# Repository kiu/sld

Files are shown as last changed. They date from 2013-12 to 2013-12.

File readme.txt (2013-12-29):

SLDongle (SLD) provides an inexpensive entry into the world of microcontroller development.
http://schoar.de/tinkering/sld

Control LEDs from host:
    1. Plug SLD into USB port
    2. Pipe 13 bytes to /src/usbhost/sldtool

Compile own application:
    - MCU = atmega88p
    - F_CPU = 12000000
    - Max size = 8192 bytes (flash) - 2048 bytes (bootloader) = 6144 bytes

Flash own application:
    1. Hold button
    2. Plug SLD into USB port
    3. Wait until host has enumarated the emulated USBasp
    4. Release button
    5. Flash your hex file (avrdude -p atmega88p -c usbasp -U flash:w:my.hex)

Directory structure:
    /pcb		Schematic and board as Eagle CAD files
    /pcb/img		Schematic and board as PNG files
    /pcb/gerber		Board as Gerber files

    /src/bootloader	Bootloader running on the device
    /src/contrib	Third party contributions
    /src/firmware	Main app running on the device
    /src/helper		Helper scripts for mass flashing
    /src/simple		A simple example app
    /src/usbhost	Host tool to control LEDs

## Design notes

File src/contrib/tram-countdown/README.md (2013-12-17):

# Tram Countdown

Checks when your tram leaves from Trappentreustr. and switches as many lights on as there are minutes left.

For e.g. Line 18 to Effnerplatz, run:

```
./tram-countdown 18 Effnerplatz
```

This runs with your Mac's system Ruby but you need to install the `mvg-live` gem:

```
sudo /usr/bin/gem install mvg-live
```

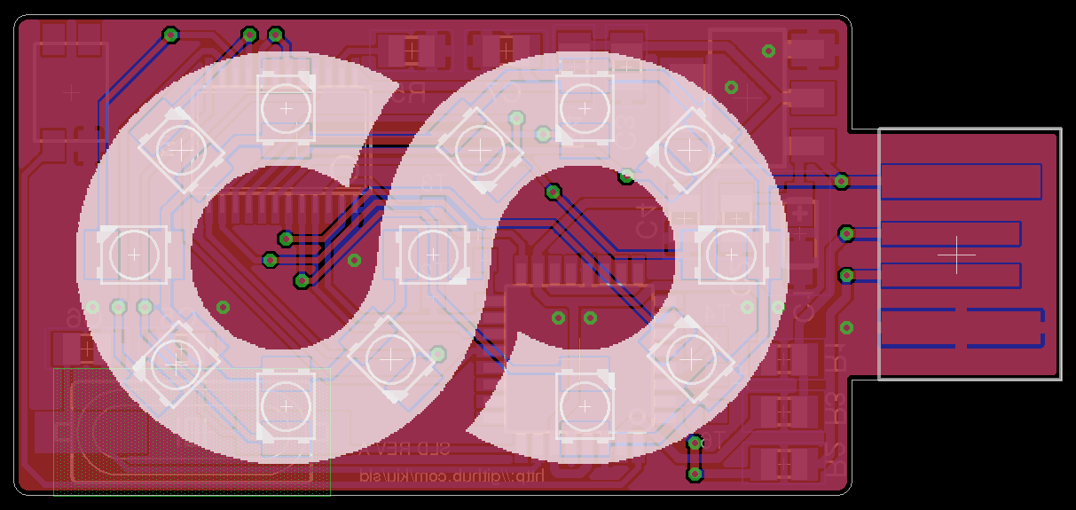
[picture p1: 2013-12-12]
pcb/img/sld_brd.png

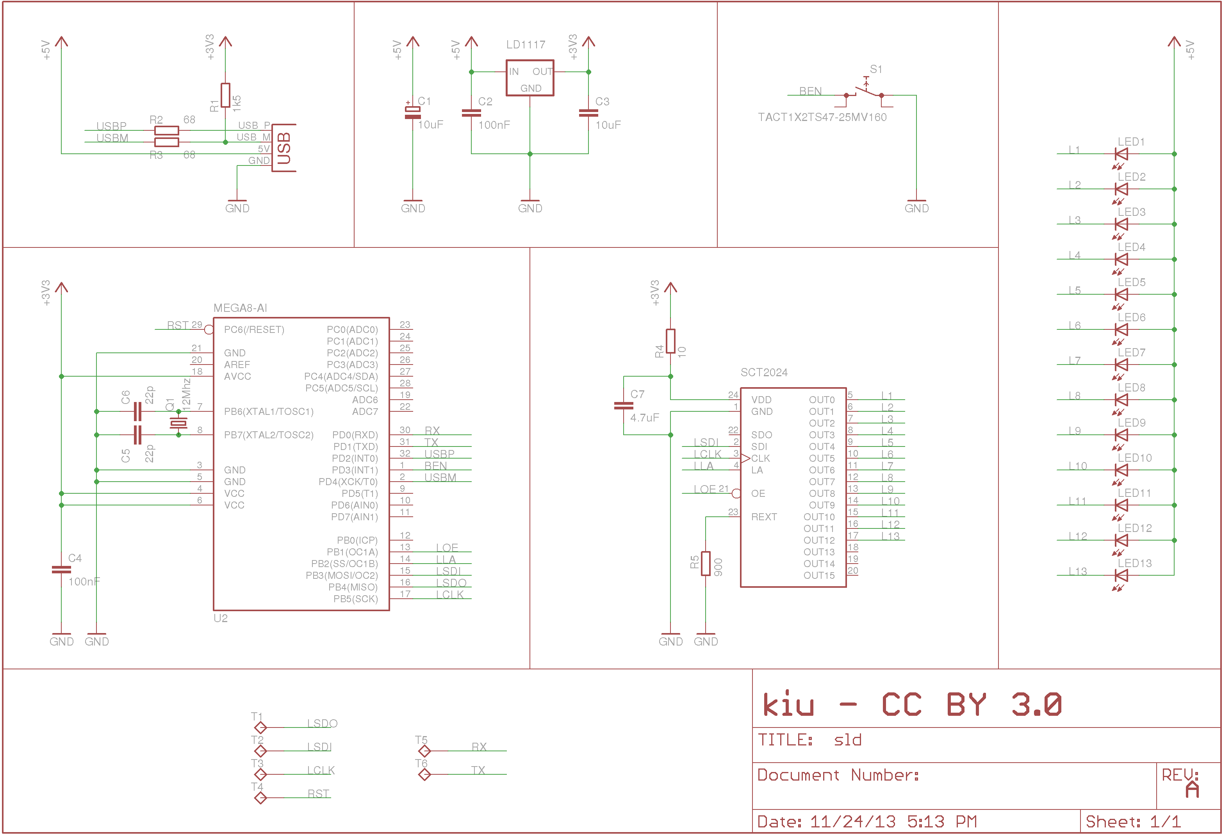
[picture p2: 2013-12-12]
pcb/img/sld_sch.png

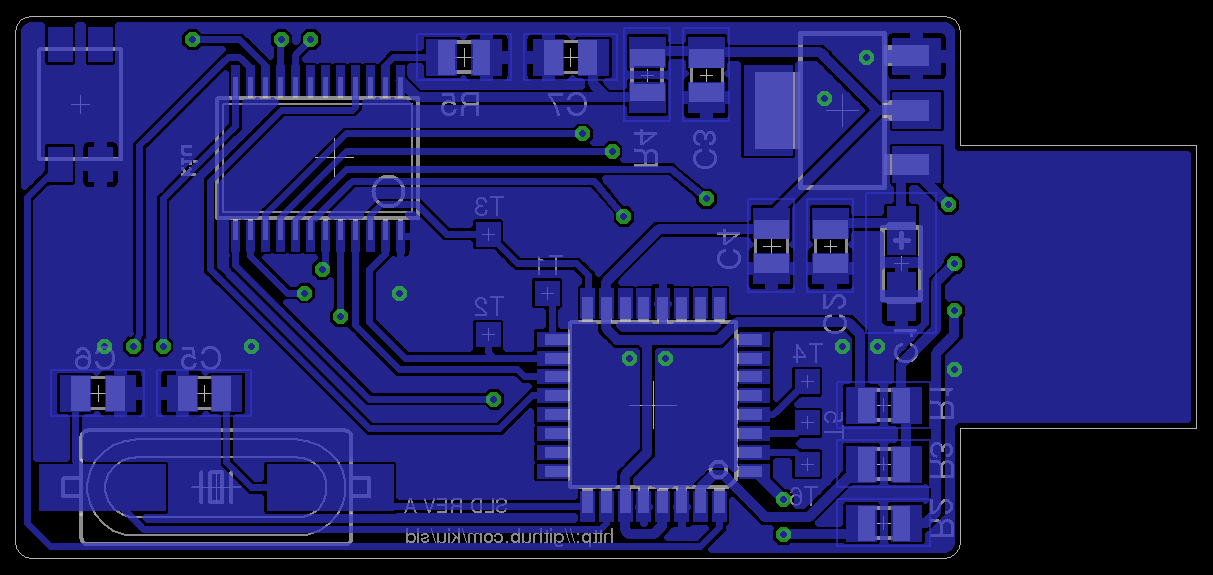
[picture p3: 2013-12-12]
pcb/img/sld_brd_btm.png

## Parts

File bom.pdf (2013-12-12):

BOM

Page 1

Ordered | Description | Qty | Price | Price (sum) | Id | Link
x | ATMega88PA-AU TQFP32 | 1 | 30 | 30 | 0.92 € | 27.63 €
x | 12Mhz crystal HC49 | 1 | 30 | 30 | 0.27 € | 8.18 €
x | 22pF 0805 | 2 | 30 | 100 | 0.01 € | 0.83 €
x | 100nF 0805 | 2 | 30 | 100 | 0.01 € | 0.60 €
x | White LED 3528 | 13 | 30 | 500 | 0.06 € | 29.75 €
x | 16 channel LED driver SSOP24 | 1 | 30 | 30 | 0.31 € | 9.28 €
x | 10R 0805 | 1 | 30 | 100 | 0.01 € | 0.71 €
x | 1k2 0805 | 1 | 30 | 100 | 0.01 € | 0.71 €
x | 4.7uF | 1 | 30 | 100 | 0.02 € | 2.02 €
x | Tactile Switch | 1 | 30 | 30 | 0.21 € | 6.25 €
x | LDO 3V3 | 1 | 30 | 30 | 0.12 € | 3.68 €
x | 10uF 0805 | 1 | 30 | 100 | 0.02 € | 1.55 €
x | | 1 | 30 | 30 | 0.07 € | 2.18 €
x | 68R 0805 | 2 | 30 | 100 | 0.01 € | 0.71 €
x | 1k5 0805 | 1 | 30 | 100 | 0.01 € | 0.71 €
x | Shipping | 1 | 1 | 1 | 5.90 € | 5.90 € | ---
x | PCB 50x50x2 blue | 1 | 30 | 1 | 88.00 € | 88.00 € | ---
| | | | | | SUM
| | | | | | 188.70 € | 6.29 €
Req | Mul
| ATMEGA88PA-AU (http://www.tme.eu/de/details/atmega88pa-au/mikrocontroller-atmel-avr-smd/atmel/) | http://www.tme.eu
| 12.00M-SMDHC49S (http://www.tme.eu/de/details/12.00m-smdhc49s/quarzresonatoren-smd/yic/) | http://www.tme.eu
| CL21C220JBANNNC (http://www.tme.eu/de/details/cl21c220jbannnc/kondensatoren-mlcc-smd-0805/samsung/) | http://www.tme.eu
| CC0805JRX7R9104 (http://www.tme.eu/de/details/cc0805jrx7r9104/kondensatoren-mlcc-smd-0805/yageo/cc0805jrx7r9bb104/) | http://www.tme.eu
| WW-WTA30TS-Q (http://www.tme.eu/de/details/ww-wta30ts-q/led-dioden-smd-plcc/wah-wang-holding/) | http://www.tme.eu
| SCT2024CSSG (http://www.tme.eu/de/details/sct2024cssg/led-treiber/starchips-technology/) | http://www.tme.eu
| RC0805FR-0710R (http://www.tme.eu/de/details/rc0805fr-0710r/widerstande-smd-0805/yageo/rc0805fr-0710rl/) | http://www.tme.eu
| SMD0805-1K2-1% (http://www.tme.eu/de/details/smd0805-1k2-1%25/widerstande-smd-0805/royal-ohm/0805s8f1201t5e/) | http://www.tme.eu
| CL21A475KOFNNNE (http://www.tme.eu/de/details/cl21a475kofnnne/kondensatoren-mlcc-smd-0805/samsung/) | http://www.tme.eu
| TS4725MV160 (http://www.tme.eu/de/details/ts4725mv160/tact-pcb-mikroschalter/canal-electronic/ts47-25mv160/) | http://www.tme.eu
| LD1117S33TR (http://www.tme.eu/de/details/ld1117s33tr/ungeregelte-spannungsstabilisatoren-ldo/st-microelectronics/) | http://www.tme.eu
| CC0805KKX5R5106 (http://www.tme.eu/de/details/cc0805kkx5r5106/kondensatoren-mlcc-smd-0805/yageo/cc0805kkx5r5bb106/) | http://www.tme.eu
10uF Tantal | TAJA106K010R (http://www.tme.eu/de/details/taja106k010r/tantal-kondensatoren-smd/avx/taja106k010rnj/) | http://www.tme.eu
| SMD0805-68R-1% (http://www.tme.eu/de/details/smd0805-68r-1%25/widerstande-smd-0805/royal-ohm/0805s8f680jt5e/) | http://www.tme.eu
| SMD0805-1K5-1% (http://www.tme.eu/de/details/smd0805-1k5-1%25/widerstande-smd-0805/royal-ohm/0805s8f1501t5e/) | http://www.tme.eu
| | http://www.tme.eu
| | http://www.seeedstudio.com
A | B | C | D | E | F | G | H | I
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
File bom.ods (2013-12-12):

Ordered | Description | Req | Mul | Qty | Price | Price (sum) | Id | Link
x | ATMega88PA-AU TQFP32 | 1 | 30 | 30 | 0.92 € | 27.63 € | ATMEGA88PA-AU (http://www.tme.eu/de/details/atmega88pa-au/mikrocontroller-atmel-avr-smd/atmel/) | http://www.tme.eu
x | 12Mhz crystal HC49 | 1 | 30 | 30 | 0.27 € | 8.18 € | 12.00M-SMDHC49S (http://www.tme.eu/de/details/12.00m-smdhc49s/quarzresonatoren-smd/yic/) | http://www.tme.eu
x | 22pF 0805 | 2 | 30 | 100 | 0.01 € | 0.83 € | CL21C220JBANNNC (http://www.tme.eu/de/details/cl21c220jbannnc/kondensatoren-mlcc-smd-0805/samsung/) | http://www.tme.eu
x | 100nF 0805 | 2 | 30 | 100 | 0.01 € | 0.60 € | CC0805JRX7R9104 (http://www.tme.eu/de/details/cc0805jrx7r9104/kondensatoren-mlcc-smd-0805/yageo/cc0805jrx7r9bb104/) | http://www.tme.eu
x | White LED 3528 | 13 | 30 | 500 | 0.06 € | 29.75 € | WW-WTA30TS-Q (http://www.tme.eu/de/details/ww-wta30ts-q/led-dioden-smd-plcc/wah-wang-holding/) | http://www.tme.eu
x | 16 channel LED driver SSOP24 | 1 | 30 | 30 | 0.31 € | 9.28 € | SCT2024CSSG (http://www.tme.eu/de/details/sct2024cssg/led-treiber/starchips-technology/) | http://www.tme.eu
x | 10R 0805 | 1 | 30 | 100 | 0.01 € | 0.71 € | RC0805FR-0710R (http://www.tme.eu/de/details/rc0805fr-0710r/widerstande-smd-0805/yageo/rc0805fr-0710rl/) | http://www.tme.eu
x | 1k2 0805 | 1 | 30 | 100 | 0.01 € | 0.71 € | SMD0805-1K2-1% (http://www.tme.eu/de/details/smd0805-1k2-1%25/widerstande-smd-0805/royal-ohm/0805s8f1201t5e/) | http://www.tme.eu
x | 4.7uF | 1 | 30 | 100 | 0.02 € | 2.02 € | CL21A475KOFNNNE (http://www.tme.eu/de/details/cl21a475kofnnne/kondensatoren-mlcc-smd-0805/samsung/) | http://www.tme.eu
x | Tactile Switch | 1 | 30 | 30 | 0.21 € | 6.25 € | TS4725MV160 (http://www.tme.eu/de/details/ts4725mv160/tact-pcb-mikroschalter/canal-electronic/ts47-25mv160/) | http://www.tme.eu
x | LDO 3V3 | 1 | 30 | 30 | 0.12 € | 3.68 € | LD1117S33TR (http://www.tme.eu/de/details/ld1117s33tr/ungeregelte-spannungsstabilisatoren-ldo/st-microelectronics/) | http://www.tme.eu
x | 10uF 0805 | 1 | 30 | 100 | 0.02 € | 1.55 € | CC0805KKX5R5106 (http://www.tme.eu/de/details/cc0805kkx5r5106/kondensatoren-mlcc-smd-0805/yageo/cc0805kkx5r5bb106/) | http://www.tme.eu
x | 10uF Tantal | 1 | 30 | 30 | 0.07 € | 2.18 € | TAJA106K010R (http://www.tme.eu/de/details/taja106k010r/tantal-kondensatoren-smd/avx/taja106k010rnj/) | http://www.tme.eu
x | 68R 0805 | 2 | 30 | 100 | 0.01 € | 0.71 € | SMD0805-68R-1% (http://www.tme.eu/de/details/smd0805-68r-1%25/widerstande-smd-0805/royal-ohm/0805s8f680jt5e/) | http://www.tme.eu
x | 1k5 0805 | 1 | 30 | 100 | 0.01 € | 0.71 € | SMD0805-1K5-1% (http://www.tme.eu/de/details/smd0805-1k5-1%25/widerstande-smd-0805/royal-ohm/0805s8f1501t5e/) | http://www.tme.eu
x | Shipping | 1 | 1 | 1 | 5.90 € | 5.90 € | --- | http://www.tme.eu
x | PCB 50x50x2 blue | 1 | 30 | 1 | 88.00 € | 88.00 € | --- | http://www.seeedstudio.com
 |  |  |  |  |  | SUM
 |  |  |  |  |  | 188.70 € | 6.29 €

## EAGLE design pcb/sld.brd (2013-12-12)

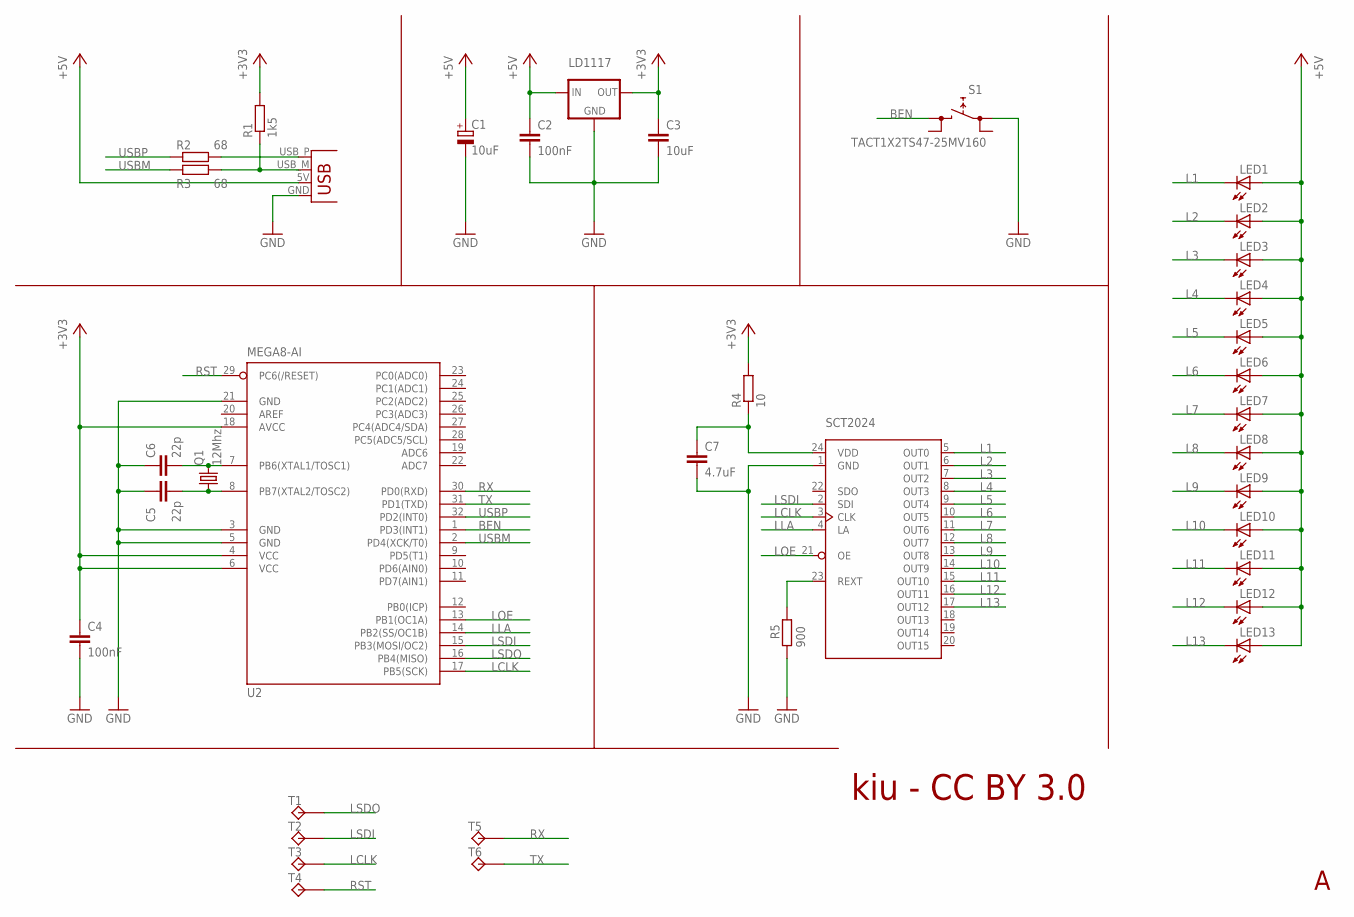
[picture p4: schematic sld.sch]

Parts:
C1: 10uF; CT3216
C2, C4: 100nF; C0805
C3: 10uF; C0805
C5, C6: 22p; C0805
C7: 4.7uF; C0805
JP1: USBPCB; USB-A-PCB
LED1, LED2, LED3, LED4, LED5, LED6, LED7, LED8, LED9, LED10, LED11, LED12, LED13: LEDKA-3528ASYC; KA-3528ASYC
Q1: 12Mhz; HC49UP
R1: 1k5; R0805
R2, R3: 68; R0805
R4: 10; R0805
R5: 900; R0805
S1: TACT1X2TS47-25MV160; TACT1.7X5.15
T1, T2, T3, T4, T5, T6: PAD; PAD-1X1
U1: LD1117; SOT223
U2: MEGA8-AI; TQFP32-08
U3: SCT2024; SSOP24

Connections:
+3V3: C3.1, C4.1, R1.2, R4.2, U1.2 (OUT), U2.4 (VCC), U2.6 (VCC), U2.18 (AVCC)
+5V: C1.+, C2.1, JP1.5V (VBUS), LED1.A, LED2.A, LED3.A, LED4.A, LED5.A, LED6.A, LED7.A, LED8.A, LED9.A, LED10.A, LED11.A, LED12.A, LED13.A, U1.3 (IN)
BEN: S1.2 (1), U2.1 (PD3(INT1))
GND: C1.-, C2.2, C3.2, C4.2, C5.1, C6.1, C7.2, JP1.GND, R5.2, S1.1 (0), U1.1 (GND), U2.3 (GND), U2.5 (GND), U2.21 (GND), U3.1 (GND)
L1: LED1.C, U3.5 (OUT0)
L2: LED2.C, U3.6 (OUT1)
L3: LED3.C, U3.7 (OUT2)
L4: LED4.C, U3.8 (OUT3)
L5: LED5.C, U3.9 (OUT4)
L6: LED6.C, U3.10 (OUT5)
L7: LED7.C, U3.11 (OUT6)
L8: LED8.C, U3.12 (OUT7)
L9: LED9.C, U3.13 (OUT8)
L10: LED10.C, U3.14 (OUT9)
L11: LED11.C, U3.15 (OUT10)
L12: LED12.C, U3.16 (OUT11)
L13: LED13.C, U3.17 (OUT12)
LCLK: T3.P1, U2.17 (PB5(SCK)), U3.3 (CLK)
LLA: U2.14 (PB2(SS/OC1B)), U3.4 (LA)
LOE: U2.13 (PB1(OC1A)), U3.21 (OE)
LSDI: T2.P1, U2.15 (PB3(MOSI/OC2)), U3.2 (SDI)
LSDO: T1.P1, U2.16 (PB4(MISO))
unnamed: C6.2, Q1.2, U2.7 (PB6(XTAL1/TOSC1))
unnamed: C5.2, Q1.1, U2.8 (PB7(XTAL2/TOSC2))
unnamed: R5.1, U3.23 (REXT)
unnamed: C7.1, R4.1, U3.24 (VDD)
unnamed: JP1.USB_P (D+), R2.2
unnamed: JP1.USB_M (D-), R1.1, R3.1
RST: T4.P1, U2.29 (PC6(/RESET))
RX: T5.P1, U2.30 (PD0(RXD))
TX: T6.P1, U2.31 (PD1(TXD))
USBM: R3.2, U2.2 (PD4(XCK/T0))
USBP: R2.1, U2.32 (PD2(INT0))

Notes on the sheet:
kiu - CC BY 3.0

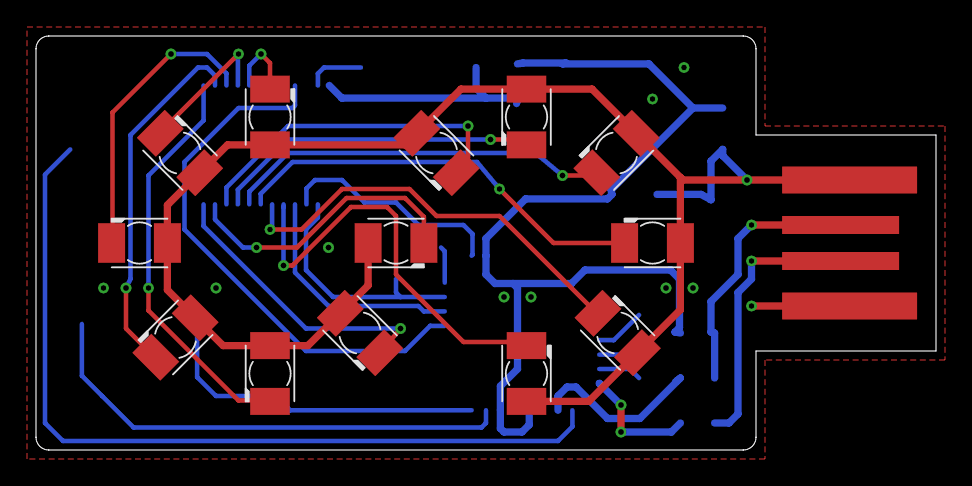
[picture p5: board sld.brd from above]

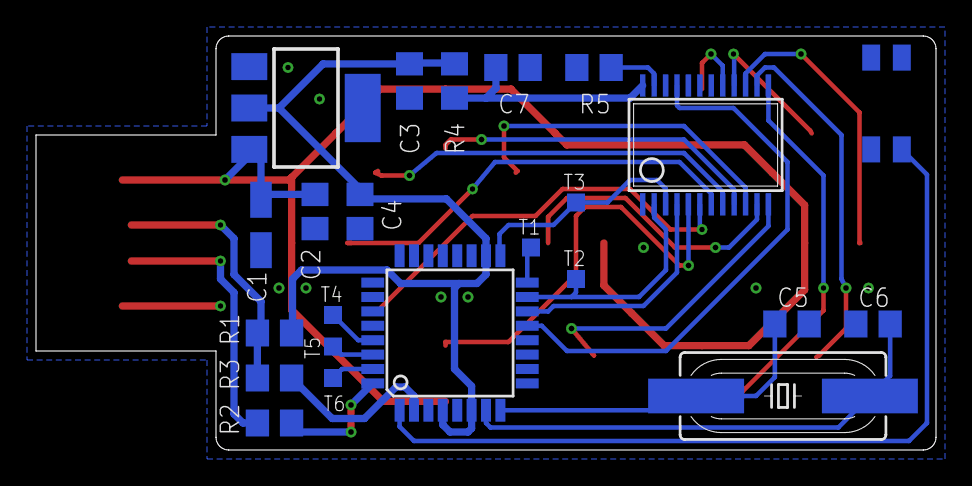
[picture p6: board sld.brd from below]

Board: 4 copper layers, 50.0 x 23.0 mm, 37 parts (23 on the bottom side), 33 nets.

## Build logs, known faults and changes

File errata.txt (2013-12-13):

REV A
    - LEDs are way to bright
    - Silkscreen print for board name and github address should be bigger
    - USB 1k5 pullup should be connected to AVR PIN (connect on demand)

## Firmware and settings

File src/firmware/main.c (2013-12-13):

// Based on hid-data from Christian Starkjohann
// http://www.obdev.at/products/vusb/index.html

#include "global.h"
#include "anim.h"

#include <avr/io.h>
#include <avr/wdt.h>
#include <avr/interrupt.h>  /* for sei() */
#include <util/delay.h>     /* for _delay_ms() */
#include <avr/eeprom.h>

#include <avr/pgmspace.h>   /* required by usbdrv.h */
#include "usbdrv.h"
#include "oddebug.h"        /* This is also an example for using debug macros */

uint8_t pwm_buf[13];

/* ------------------------------------------------------------------------- */
/* ----------------------------- USB interface ----------------------------- */
/* ------------------------------------------------------------------------- */

PROGMEM const char usbHidReportDescriptor[22] = {    /* USB report descriptor */
    0x06, 0x00, 0xff,              // USAGE_PAGE (Generic Desktop)
    0x09, 0x01,                    // USAGE (Vendor Usage 1)
    0xa1, 0x01,                    // COLLECTION (Application)
    0x15, 0x00,                    //   LOGICAL_MINIMUM (0)
    0x26, 0xff, 0x00,              //   LOGICAL_MAXIMUM (255)
    0x75, 0x08,                    //   REPORT_SIZE (8)
    0x95, 0x0D,                    //   REPORT_COUNT (13)
    0x09, 0x00,                    //   USAGE (Undefined)
    0xb2, 0x02, 0x01,              //   FEATURE (Data,Var,Abs,Buf)
    0xc0                           // END_COLLECTION
};
/* Since we define only one feature report, we don't use report-IDs (which
 * would be the first byte of the report). The entire report consists of 128
 * opaque data bytes.
 */

/* The following variables store the status of the current data transfer */
static uchar    currentAddress;
static uchar    bytesRemaining;

/* ------------------------------------------------------------------------- */

/* usbFunctionRead() is called when the host requests a chunk of data from
 * the device. For more information see the documentation in usbdrv/usbdrv.h.
 */
uchar   usbFunctionRead(uchar *data, uchar len) {
    if(len > bytesRemaining)
        len = bytesRemaining;

    //eeprom_read_block(data, (uchar *)0 + currentAddress, len);
    int i;
    for (i = 0; i < len; i++) {
	*data = pwm_buf[currentAddress + i];
	data++;
    }

    currentAddress += len;
    bytesRemaining -= len;
    return len;
}


/* usbFunctionWrite() is called when the host sends a chunk of data to the
 * device. For more information see the documentation in usbdrv/usbdrv.h.
 */
uchar   usbFunctionWrite(uchar *data, uchar len) {
    if(bytesRemaining == 0) {
        return 1;               /* end of transfer */
    }
    if(len > bytesRemaining)
        len = bytesRemaining;

    //eeprom_write_block(data, (uchar *)0 + currentAddress, len);
    int i;
    for (i = 0; i < len; i++) {
	pwm_buf[currentAddress + i] = *data;
	data++;
    }

    currentAddress += len;
    bytesRemaining -= len;

    if(bytesRemaining == 0) {
	animSetPWM(pwm_buf);
    }

    return bytesRemaining == 0; /* return 1 if this was the last chunk */
}

/* ------------------------------------------------------------------------- */

usbMsgLen_t usbFunctionSetup(uchar data[8]) {
usbRequest_t    *rq = (void *)data;

    if((rq->bmRequestType & USBRQ_TYPE_MASK) == USBRQ_TYPE_CLASS){    /* HID class request */
        if(rq->bRequest == USBRQ_HID_GET_REPORT){  /* wValue: ReportType (highbyte), ReportID (lowbyte) */
            /* since we have only one report type, we can ignore the report-ID */
            bytesRemaining = 13;
            currentAddress = 0;
            return USB_NO_MSG;  /* use usbFunctionRead() to obtain data */
        }else if(rq->bRequest == USBRQ_HID_SET_REPORT){
            /* since we have only one report type, we can ignore the report-ID */
            bytesRemaining = 13;
            currentAddress = 0;
            return USB_NO_MSG;  /* use usbFunctionWrite() to receive data from host */
        }
    }else{
        /* ignore vendor type requests, we don't use any */
    }
    return 0;
}

/* ------------------------------------------------------------------------- */

volatile uint16_t btn = 0;

ISR (INT1_vect) {
    EIMSK &= ~(1 << INT1); // Disable INT1
    btn = 1;
}

void handleButton() {
	if (btn == 0) {
	    return;
	}

	if (btn == 1) {
	    animNext();
	}

	btn++;
	if (btn == 0x2FFF) {
	    btn = 0;
	    EIMSK |= (1 << INT1); // Enable INT1
	}
}

/* ------------------------------------------------------------------------- */

void initHW() {
        // Prepare Ports
        sbi(DDRB, PB1);  // LED Output Enable Out
        sbi(DDRB, PB2);  // LED Latch Out
        sbi(DDRB, PB3);  // LED MOSI Out
        sbi(DDRB, PB5);  // LED SCK Out

        cbi(DDRD, PD3);  // Button In
        sbi(PORTD, PD3);  // Button In Pullup

        // Prepare SPI
        SPCR = (1 << MSTR) | (1 << SPE); // clk/4
        SPSR |= (1 << SPI2X);

        cbi(PORTB, PB1);  // LED Output Enable On

        EIMSK = 1 << INT1; // Enable INT1
}

int main(void) {

    initHW();

    uchar   i;

    wdt_enable(WDTO_1S);
    /* Even if you don't use the watchdog, turn it off here. On newer devices,
     * the status of the watchdog (on/off, period) is PRESERVED OVER RESET!
     */
    /* RESET status: all port bits are inputs without pull-up.
     * That's the way we need D+ and D-. Therefore we don't need any
     * additional hardware initialization.
     */
    odDebugInit();
    DBG1(0x00, 0, 0);       /* debug output: main starts */
    usbInit();
    usbDeviceDisconnect();  /* enforce re-enumeration, do this while interrupts are disabled! */
    i = 0;
    while(--i){             /* fake USB disconnect for > 250 ms */
        wdt_reset();
        _delay_ms(1);
    }
    usbDeviceConnect();
    sei();
    DBG1(0x01, 0, 0);       /* debug output: main loop starts */

    for(;;){                /* main event loop */
        DBG1(0x02, 0, 0);   /* debug output: main loop iterates */
        wdt_reset();
        usbPoll();
	handleButton();
	animTick();
    }
    return 0;

}

/* ------------------------------------------------------------------------- */

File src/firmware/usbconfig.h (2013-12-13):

/* Name: usbconfig.h
 * Project: V-USB, virtual USB port for Atmel's(r) AVR(r) microcontrollers
 * Author: Christian Starkjohann
 * Creation Date: 2005-04-01
 * Tabsize: 4
 * Copyright: (c) 2005 by OBJECTIVE DEVELOPMENT Software GmbH
 * License: GNU GPL v2 (see License.txt), GNU GPL v3 or proprietary (CommercialLicense.txt)
 */

#ifndef __usbconfig_h_included__
#define __usbconfig_h_included__

/*
General Description:
This file is an example configuration (with inline documentation) for the USB
driver. It configures V-USB for USB D+ connected to Port D bit 2 (which is
also hardware interrupt 0 on many devices) and USB D- to Port D bit 4. You may
wire the lines to any other port, as long as D+ is also wired to INT0 (or any
other hardware interrupt, as long as it is the highest level interrupt, see
section at the end of this file).
*/

/* ---------------------------- Hardware Config ---------------------------- */

#define USB_CFG_IOPORTNAME      D
/* This is the port where the USB bus is connected. When you configure it to
 * "B", the registers PORTB, PINB and DDRB will be used.
 */
#define USB_CFG_DMINUS_BIT      4
/* This is the bit number in USB_CFG_IOPORT where the USB D- line is connected.
 * This may be any bit in the port.
 */
#define USB_CFG_DPLUS_BIT       2
/* This is the bit number in USB_CFG_IOPORT where the USB D+ line is connected.
 * This may be any bit in the port. Please note that D+ must also be connected
 * to interrupt pin INT0! [You can also use other interrupts, see section
 * "Optional MCU Description" below, or you can connect D- to the interrupt, as
 * it is required if you use the USB_COUNT_SOF feature. If you use D- for the
 * interrupt, the USB interrupt will also be triggered at Start-Of-Frame
 * markers every millisecond.]
 */
#define USB_CFG_CLOCK_KHZ       (F_CPU/1000)
/* Clock rate of the AVR in kHz. Legal values are 12000, 12800, 15000, 16000,
 * 16500, 18000 and 20000. The 12.8 MHz and 16.5 MHz versions of the code
 * require no crystal, they tolerate +/- 1% deviation from the nominal
 * frequency. All other rates require a precision of 2000 ppm and thus a
 * crystal!
 * Since F_CPU should be defined to your actual clock rate anyway, you should
 * not need to modify this setting.
 */
#define USB_CFG_CHECK_CRC       0
/* Define this to 1 if you want that the driver checks integrity of incoming
 * data packets (CRC checks). CRC checks cost quite a bit of code size and are
 * currently only available for 18 MHz crystal clock. You must choose
 * USB_CFG_CLOCK_KHZ = 18000 if you enable this option.
 */

/* ----------------------- Optional Hardware Config ------------------------ */

/* #define USB_CFG_PULLUP_IOPORTNAME   D */
/* If you connect the 1.5k pullup resistor from D- to a port pin instead of
 * V+, you can connect and disconnect the device from firmware by calling
 * the macros usbDeviceConnect() and usbDeviceDisconnect() (see usbdrv.h).
 * This constant defines the port on which the pullup resistor is connected.
 */
/* #define USB_CFG_PULLUP_BIT          4 */
/* This constant defines the bit number in USB_CFG_PULLUP_IOPORT (defined
 * above) where the 1.5k pullup resistor is connected. See description
 * above for details.
 */

/* --------------------------- Functional Range ---------------------------- */
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

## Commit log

2013-12-11 Minimalist sample
2013-12-12 500mA power
2013-12-12 Adapted makefile to mcu, programmer, fuses, ...
2013-12-12 Stay in bootloader even though button is released
2013-12-12 Bill Of Materials for REV A
    [bom.ods]
2013-12-12 Adding REV A board
    [sld.GBL, sld.GBO, sld.GBP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]
2013-12-13 Faster startup time (fuse)
2013-12-13 Adding HW PWM for LEDs

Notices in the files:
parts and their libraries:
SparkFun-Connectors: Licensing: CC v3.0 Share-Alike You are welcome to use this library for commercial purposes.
